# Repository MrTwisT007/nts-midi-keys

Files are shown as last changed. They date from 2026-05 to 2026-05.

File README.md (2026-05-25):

# What is this?
This is a project for a mini MIDI keyboard attachment for the Korg NTS-1 mini synthesizer I made circa 2021. It has two octaves of keys with octave switch buttons on either end. 

# What's in it?
This repo contains the KICAD files, arduino sketch to program the ATTiny45 and 3D stl files for the body attachment. I used an arduino mini to program the ATTiny as I did not have a suitable programmer at the time. Note, due to an error the footprint of the ATTiny is too narrow to fit the SOP package. Either edit the project file, or bend the pins of the MCU to fit it onto the board.

# Photos





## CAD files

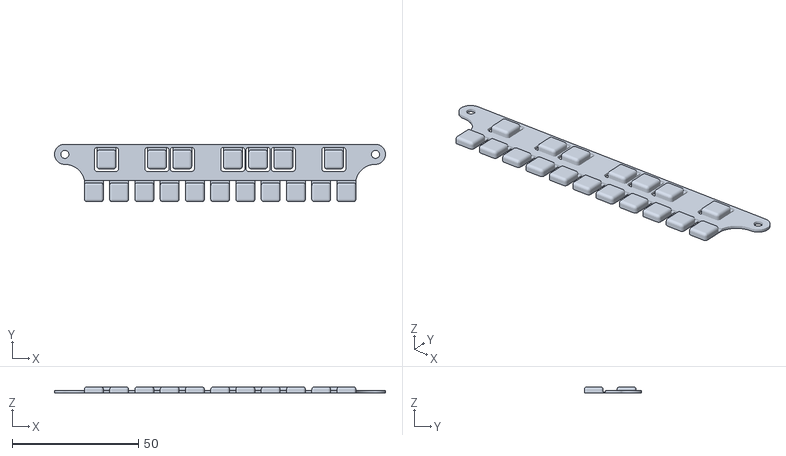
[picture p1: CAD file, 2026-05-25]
stl/keys_overlay.stl
131.0 x 22.7 x 2.50

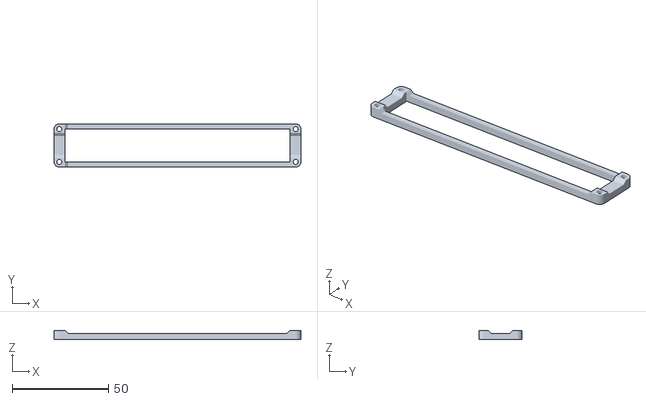
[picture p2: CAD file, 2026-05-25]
stl/keys_spacer.stl
128.5 x 22.5 x 4.75

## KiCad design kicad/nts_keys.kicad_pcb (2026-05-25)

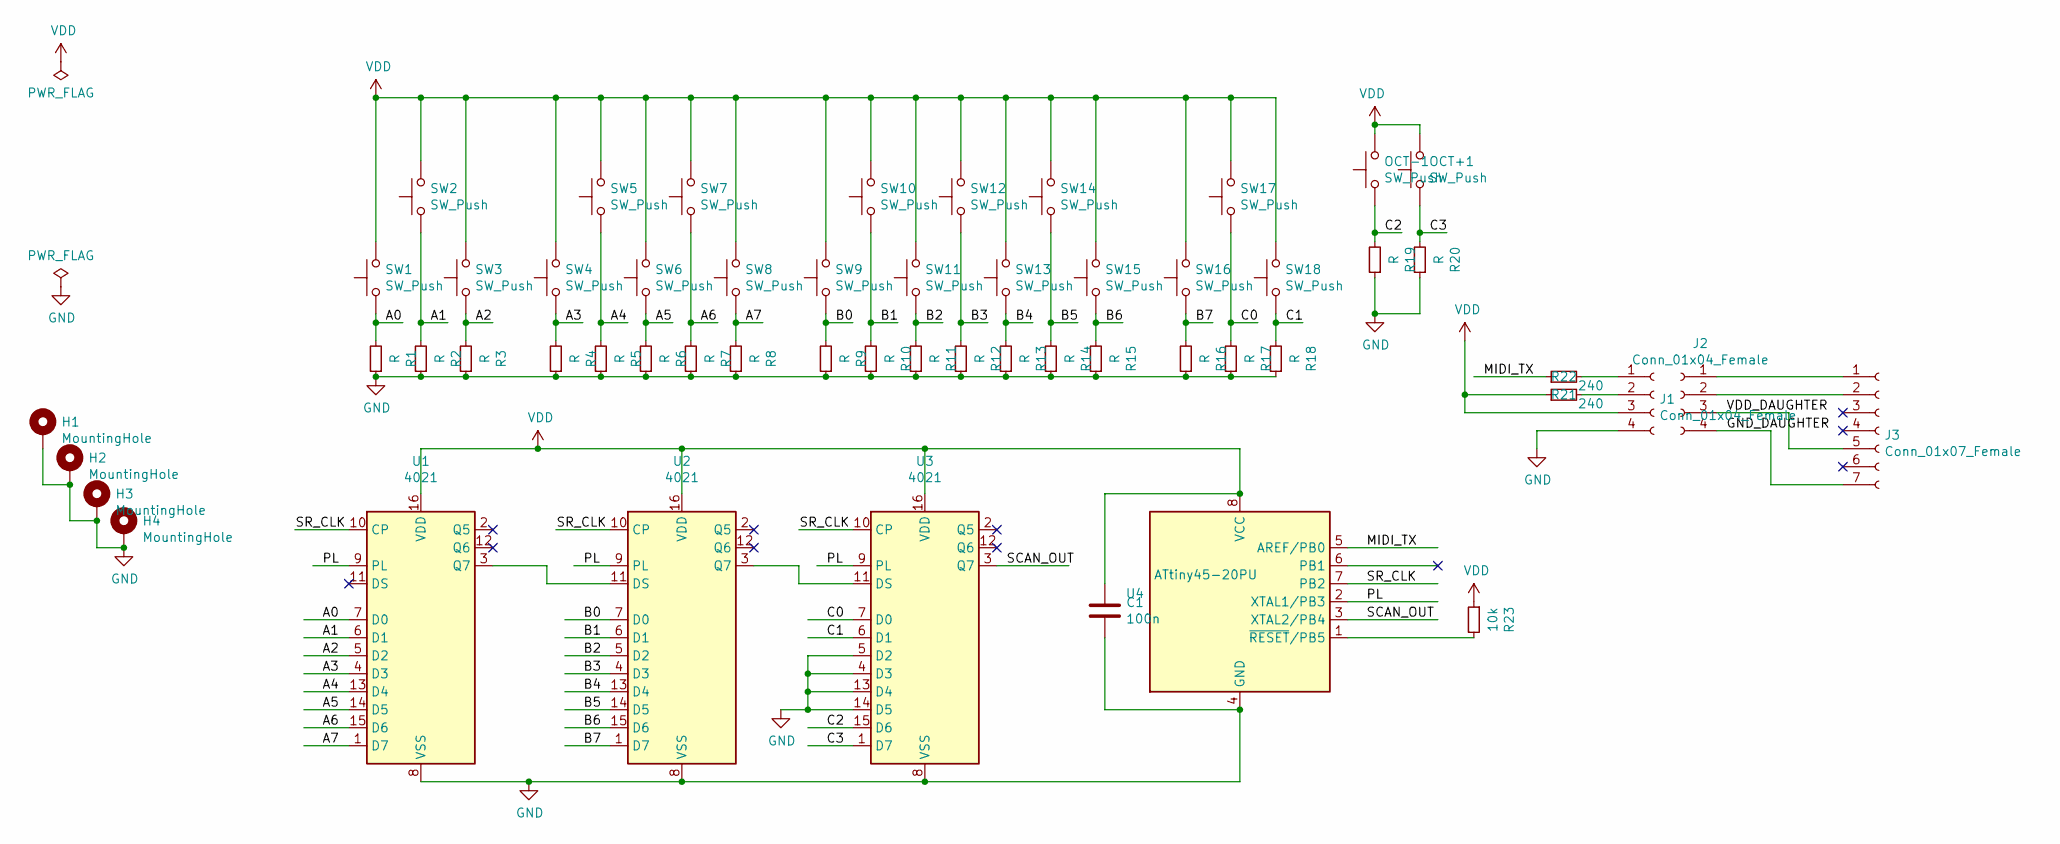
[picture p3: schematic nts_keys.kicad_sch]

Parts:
C1: 100n; C_1206_HandSoldering
H1, H2, H3, H4: MountingHole; MountingHole_3mm_Pad
J1, J2: Conn_01x04_Female; TE_84952-4_1x04_P1.0mm_Horizontal
J3: Conn_01x07_Female; Pin_Header_Straight_1x07_Pitch2.54mm
OCT+1: SW_Push; SW_SPST_EVQQ2
OCT-1: SW_Push; SW_SPST_EVQQ2
R1, R2, R3, R4, R5, R6, R7, R8, R9, R10, R11, R12, R13, R14, R15, R16, R17, R18, R19, R20: R; R_1206_HandSoldering
R21, R22: 240; R_1206_HandSoldering
R23: 10k; R_1206_HandSoldering
SW1, SW2, SW3, SW4, SW5, SW6, SW7, SW8, SW9, SW10, SW11, SW12, SW13, SW14, SW15, SW16, SW17, SW18: SW_Push; SW_SPST_EVQQ2
U1, U2, U3: 4021; SOIC-16_3.9x9.9mm_Pitch1.27mm
U4: ATtiny45-20PU; SOIJ-8_5.3x5.3mm_Pitch1.27mm

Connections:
/A0: R1.2, SW1.1, U1.7 (D0)
/A1: R2.2, SW2.1, U1.6 (D1)
/A2: R3.2, SW3.1, U1.5 (D2)
/A3: R4.2, SW4.1, U1.4 (D3)
/A4: R5.2, SW5.1, U1.13 (D4)
/A5: R6.2, SW6.1, U1.14 (D5)
/A6: R7.2, SW7.1, U1.15 (D6)
/A7: R8.2, SW8.1, U1.1 (D7)
/B0: R9.2, SW9.1, U2.7 (D0)
/B1: R10.2, SW10.1, U2.6 (D1)
/B2: R11.2, SW11.1, U2.5 (D2)
/B3: R12.2, SW12.1, U2.4 (D3)
/B4: R13.2, SW13.1, U2.13 (D4)
/B5: R14.2, SW14.1, U2.14 (D5)
/B6: R15.2, SW15.1, U2.15 (D6)
/B7: R16.2, SW16.1, U2.1 (D7)
/C0: R17.2, SW17.1, U3.7 (D0)
/C1: R18.2, SW18.1, U3.6 (D1)
/C2: OCT-1.1, R19.2, U3.15 (D6)
/C3: OCT+1.1, R20.2, U3.1 (D7)
/GND_DAUGHTER: J2.4, J3.7
/MIDI_TX: R22.1, U4.5 (AREF/PB0)
/PL: U1.9 (PL), U2.9 (PL), U3.9 (PL), U4.2 (XTAL1/PB3)
/SCAN_OUT: U3.3 (Q7), U4.3 (XTAL2/PB4)
/SR_CLK: U1.10 (CP), U2.10 (CP), U3.10 (CP), U4.7 (PB2)
/VDD_DAUGHTER: J2.3, J3.5
GND: C1.2, H1.1, H2.1, H3.1, H4.1, J1.4, R1.1, R2.1, R3.1, R4.1, R5.1, R6.1, R7.1, R8.1, R9.1, R10.1, R11.1, R12.1, R13.1, R14.1, R15.1, R16.1, R17.1, R18.1, R19.1, R20.1, U1.8 (VSS), U2.8 (VSS), U3.4 (D3), U3.5 (D2), U3.8 (VSS), U3.13 (D4), U3.14 (D5), U4.4 (GND)
unnamed: J1.1, R22.2
unnamed: J1.2, R21.2
unnamed: J2.1, J3.1
unnamed: J2.2, J3.2
unnamed: U1.3 (Q7), U2.11 (DS)
unnamed: U2.3 (Q7), U3.11 (DS)
unnamed: R23.2, U4.1 (~RESET/PB5)
VDD: C1.1, J1.3, OCT+1.2, OCT-1.2, R21.1, R23.1, SW1.2, SW2.2, SW3.2, SW4.2, SW5.2, SW6.2, SW7.2, SW8.2, SW9.2, SW10.2, SW11.2, SW12.2, SW13.2, SW14.2, SW15.2, SW16.2, SW17.2, SW18.2, U1.16 (VDD), U2.16 (VDD), U3.16 (VDD), U4.8 (VCC)

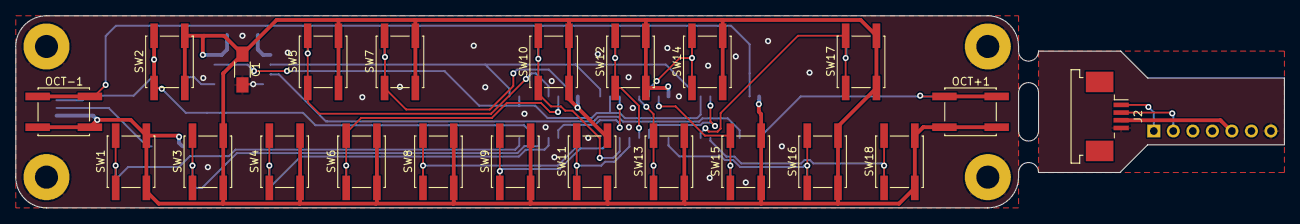
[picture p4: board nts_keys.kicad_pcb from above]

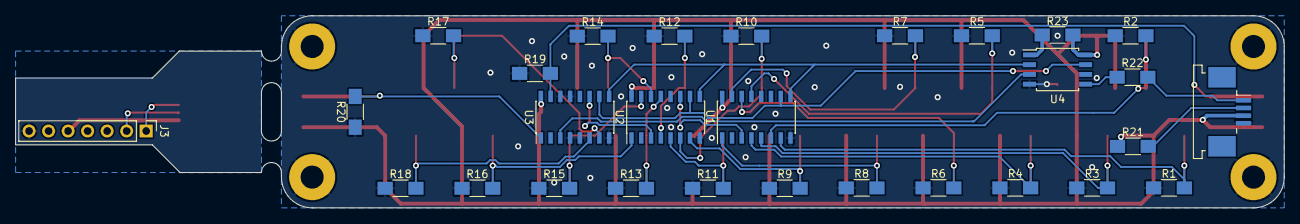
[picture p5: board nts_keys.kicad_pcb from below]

Board: 2 copper layers, 165.1 x 25.0 mm, 55 parts (29 on the bottom side), 35 nets.

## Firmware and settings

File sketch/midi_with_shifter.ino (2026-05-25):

#include <MIDI.h>
#include <midi_Defs.h>
#include <midi_Message.h>
#include <midi_Namespace.h>
#include <midi_Settings.h>

#define NUM_SHIFTERS 3
#define NUM_BUTTONS 18
#define CLOCK 2
#define PLATCH 3
#define DATAIN 4
#define OCTAVE 12
#define STARTNOTE 21
#define OCT_MAX 8

// Won't be handling SYSEX
struct MySettings : public MIDI_NAMESPACE::DefaultSettings
{
   static const unsigned SysExMaxSize = 0;
};
MIDI_CREATE_CUSTOM_INSTANCE(TinySoftwareSerial, Serial, MIDI, MySettings)

byte scanin[NUM_SHIFTERS];  //scanin data from shift reg
byte scanin_p[NUM_SHIFTERS];//previous scanin data
byte oct_transp = 2;        //transpose/oct offset
bool switch_oct = false;
byte num_latched_keys = 0;
byte latch_list[NUM_BUTTONS];

void setup()
{
  bitWrite(DDRB, CLOCK, 1);   //clock
  bitWrite(DDRB, PLATCH, 1);  //parallel_serialn latch
  bitWrite(DDRB, DATAIN, 0);  //data_in
  MIDI.begin(1);
  for (int i = 0; i < NUM_BUTTONS; i++) {
    latch_list[i] = 0xFF;
  }
}

void loop()
{
  latchdata(PLATCH);
  switch_oct = false;
  for(int shiftreg = NUM_SHIFTERS-1; shiftreg >= 0; shiftreg--) {
    scanin[shiftreg] = 0;
    for(int i = 7; i >= 0; i--) {
      bitWrite(PORTB, CLOCK, 0);
      delayMicroseconds(0.2);
      scanin[shiftreg] = scanin[shiftreg] | (bitRead(PINB,DATAIN) << i);
      if (shiftreg == NUM_SHIFTERS-1 && i >=6) {
        //if one of the transpose keys is pressed, we need to remember the octave offset of any pressed keys
        switch_oct = bitRead(PINB,DATAIN) ? true : switch_oct;
      } else {
        if (bitRead(PINB,DATAIN) && switch_oct) {
          if (latch_list[shiftreg*8+i] == 0xFF) {
            latch_list[shiftreg*8+i] = oct_transp;
            num_latched_keys++;
          }
        }
      }
      bitWrite(PORTB, CLOCK, 1);
    }
  }

  for(int shiftreg = 0; shiftreg < NUM_SHIFTERS; shiftreg++) {
    for(int i = 0; i < 8; i++) {
      if (bitRead(scanin[shiftreg],i) != bitRead(scanin_p[shiftreg],i)) {
        bitWrite(scanin_p[shiftreg],i, bitRead(scanin[shiftreg],i));
        if ((shiftreg == NUM_SHIFTERS-1) && (i >= 6)) {
          if (i == 6 && bitRead(scanin_p[shiftreg],i)){
            if (oct_transp > 0) {
              oct_transp -= bitRead(scanin_p[shiftreg],i);
            }
          }
          if (i == 7 && bitRead(scanin_p[shiftreg],i)) {
            if (oct_transp < OCT_MAX) {
              oct_transp += bitRead(scanin_p[shiftreg],i);
            }
          }
        } else {
          if (bitRead(scanin_p[shiftreg],i) && (latch_list[shiftreg*8+i] != oct_transp || latch_list[shiftreg*8+i] == 0xFF)) {
            MIDI.sendNoteOn(STARTNOTE+ OCTAVE*oct_transp + shiftreg*8+i, 127, 1);
          } else {
            if (num_latched_keys > 0 && latch_list[shiftreg*8+i] != 0xFF) {
              MIDI.sendNoteOff(STARTNOTE+ OCTAVE*latch_list[shiftreg*8+i] + shiftreg*8+i, 127, 1);
              num_latched_keys--;
              latch_list[shiftreg*8+i] = 0xFF;
            } else {
              MIDI.sendNoteOff(STARTNOTE+ OCTAVE*oct_transp + shiftreg*8+i, 127, 1);
            }
          }
        }
      }
    }
  }
}

void latchdata(int latchpin) {
  bitWrite(PORTB, PLATCH, 1);
  delayMicroseconds(20);
  bitWrite(PORTB, PLATCH, 0);
}
